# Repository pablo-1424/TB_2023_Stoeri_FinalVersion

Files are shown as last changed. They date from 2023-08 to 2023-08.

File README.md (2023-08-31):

# TB_2023_Stoeri_Public

## Information about the project

The goal of the project is to implement a system wich can detect if water is flowing and calculating for how long through a pipe. The amount of time of the water flow is then transmitted to TTN using the LoRa protocol.

A python script is able to store the received amount of time in a mySQL database from where two different graphs can be done.

## Used material

Chip : Murata CMWX1ZZABZ-091

Sensor : Bosch BMA400

DevKit with the Murata chip : B-L072Z-LRWAN1

DevKit with the sensor : SparkFun Triple Axis Accelerometer Breakout - BMA400

## Used software

IT-SDK from disk91 : https://github.com/disk91/stm32-it-sdk

## Content of the repository

### Folder 01_Report :

Contains the report of the thesis

### Folder 02_Code :

#### Folder EmbeddedSystem :

* Folder TB_noLoRa : Contains a functionnal code without the LoRa transmission
    
* Folder TB_Stoeri_FinalCode : Contains the final code including the LoRa transmission
  
#### Folder PythonScript :
  
* Folder SerialToGraph : Contains a code to make graphs with UART data
    
* Folder toFromSQL : Contains all the steps from TTN to dashboards threw a mySQL database

### Folder 03_Electronics :

  Contains the schematics of the PCB that has been made and wich is now used

### Folder 04_Mecanics :

  Contains all the CAD files of hardware used for this specific thesis

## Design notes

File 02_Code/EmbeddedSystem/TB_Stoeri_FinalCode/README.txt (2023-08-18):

Important files :
        Folder core/inc
                main.h : Main file, goToSleep function, timFunc function, and defines concerning the accelerometer and the water detection
                bma400func.h : Functions for the accelerometer
        
        Folder core/inc/it_sdk
                config.h : Configuration of the SDK
                configLoRaWan.h : LoRa configuration with SDK
                
        Folder core/src
                main.c : Main file, goToSleep function, and timFunc function
                project_main.c : LoRa send and Init
                bma400func.c : Functions for the accelerometer
                
        Folder stm32-it-sdk/src/stm32l_sdk
                gpio_wrapper.c : EXTI Pin12 callback
                
        Folder stm32-it-sdk/src/stm32l_sdk/timer
                timer.c : TIM6 callback
                
Startup procedure to program the final prototype :
        1) Open STM32 Cube IDE, ideally V1.9.0
        2) Import the project sensorLoRaSDK
        3) Compile in Release mode
        4) Wire the ST-Link V3 with the prototype
        5) Power the prototype
        6) With the STM32CubeProgrammer, connect the device to the PC
        7) Program the device with the .elf file wich has been generated by the compilation
        8) Connect an UART on the device (J2 connector -> See schematics)
        9) control that everything is working well

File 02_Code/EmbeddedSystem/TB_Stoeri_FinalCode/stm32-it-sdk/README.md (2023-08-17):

 Disk91 IoT_SDK not only for STM32

*Version 1.7 - in development. For stable version go to version-1.6 branch*

This project is a low level SDK with a harwdare abstraction layer designed to make IoT project. The purpose is to quickly be able to create communicating IoT device over LPWAN (LoRaWAn, Sigfox...) for fast prototyping but also being able to bring that firmware to production will all the necessary components avaoilable out-of-the-box. This SDK try to be fully configurable with header files. The objectif is to propose an abstraction layer between the software implementation and the MCU execution allowing to port the firmware on different plateform. 

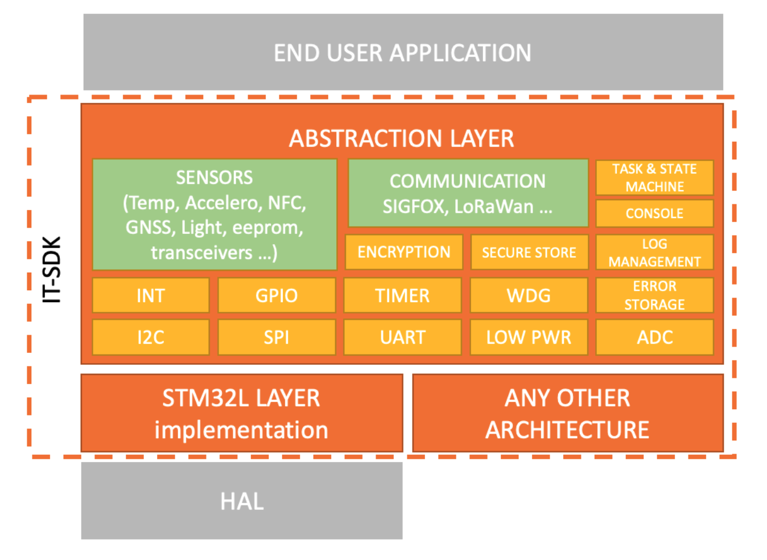
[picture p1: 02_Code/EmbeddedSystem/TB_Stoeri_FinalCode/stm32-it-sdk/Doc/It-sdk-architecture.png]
itsdk_architecture
 "IT-SDK Architecture"

The SDK is currently implementing STM32L architecture. The abstraction layer allows to quickly add new platforms. 

It implements different usefull function with (I hope) a cleaner code than the usual ST SDK components. 

Most is done to preserve code size, the SDK can target small flash MCU from 16KB for simple applications.

* IDE environement
  * open-source environment GCC / AC6 (Eclipse)
  * CubeIDE environment GCC / AC6 (Eclipse)
  * May work with any others

* Supported MCU functions
  * Low Power switch with regular auto-wakeup / LPUART / UART /GPIO Wake-up
  * RTC with calibration
  * EEprom for configuration backup
  * Watchdog 
  * Timers with calibration (hardware & software)
  * GPIO / SPI / I2C abstraction
  * Time update
  * Generic Interrupt Handler (hardware independant)

* Supported Advanced features
  * Task Scheduler
  * State Machine 
  * Multiple Serial console logger including Segger RTT
  * Error logger with NVM storage
  * Secured debug & configuration Console
  * Secured Storage in EEPROM for keys
  * End 2 End Sigfox & LoRaWan encryption
  * Configuration over serial for ID commissionning during manufacturing process
  * Accelerometer abstraction layer
  * Gnss abstraction layer
  
* Communication protocols interface
  * Sigfox ( clear-text, AES128-CTR, SPECK32, Sigfox-EAS128-CTR-Encryption )
  * LoRaWan ( LoRaWan-Encryption, EAS128-CTR, SPECK32 ) - join / uplink / downlink / ack

* Supported / tested platforms
  * STM32L011
  * STM32L053
  * STM32L072
  * STM32L052
  * MURATA CMWX1ZZABZ

* Supported drivers
  * eeprom
     * m95640
  * sigfox
     * s2lp (tested on RCZ1)
     * murata cmwx1zzabz (sx1276) (tested on RCZ1 & RCZ2)
  * lorawan
    * murata cmwx1zzabz (sx1276)
  * T / H / P
     * bosh bme280 & bmp280
     * omron 2smpb-02B
     * infineon DPS422
  * Light
     * Maxim Max44009
  * Current / Battery Pack
    * Maxim Max17205 / Max17201
  * NFC
  	 * ST25DV - block access / serial console over FTM & memory
  * Hall Effect
     * sl353
  * Accelerometer
     * STM - LIS2DH12
  * Gnss
     * Quectel L80 / L86
     * MediaTek 3333
       
* Supported stacks
  * lorawan
     * semtech stack
  * sigfox
     * sigfox stack

The second objective is to be able to port this SDK to different patform
to make it a portable SDK. The SDK have a it-sdk directory where everything needs to be portable. stm32l-sdk contains all the subfunctions specific to this platform.

# Project organization
Previously the devel branch was the living branch and master was stable. This way sound not optimal (at least for my github commit graph ;)/ So starting in 1.6 here is the new organization:
- devel is a bit advanced on master for not yet tested commit
- master is the new devel branch containing tested commit but not yet verified, you **must not** go in production with master.
- version branch for each new version + release 

# Start your project by configuring a skeleton with Cube Mx 

* Sys Clock Mux : HSI16
* Watchdog : configure IWDG with LSI 37KHz, IWDG_WINDOW value 4095, IWDG_PRESCALER value 256
* Rtc timer : TIM21 is enable with clock source internal for calibration
* LowPower : 
  * LPUART1/USART1/USART2 (Async 9600 - 8/N/1) for WakeUp => clock setting needs to be HSI and max speed needs to be 9600
  * RTC WakeUp => Activate ClkSource, Calendar, Internal WakeUp, Clk config : LSI, RTC/NVIC => Interrupt activated, Async prediv: 127, Sync prediv: 255
  * GPIO WakeUp => Activate the GPIO as ExtInterrupt, set with Pull & Trigger en Fall/Rise, activate NVIC EXI1_15
* adc : Select an adc like for temperature and Vcc to get the needed headers

When generating the Project
* Code generator:
  * select Generate peripheral initalization as par of .c/.h
  * Set all free pins as analog
* Advanced Settings:
  * Check Not Generated Function Call for ADC

# Import the SDK (this repository)

1. Clone this repository into the root of your project.
2. For the next configuration, you need to do it ifor both Debug *and* Release configuration 
3. Add in project properties >> C/C++ General >> Path&Symbol >> Source location >> the repository ItSdk Src directory.
4. Add in project properties >> C/C++ Build >> Settings >> Tool Settings >> MCU GCC Compiler >> Includes Path >>  Add the ItSdk Inc directory.
5. Add in project properties >> C/C++ Build >> Settings >> Tool Settings >> MCU GCC Assembler >> Includes Path >> Add the ItSdk Inc directory.
6. In C/C++ Build / Settings / Build Step / pre-build steps you can add the command _touch "${workspace_loc:/${ProjName}/stm32-it-sdk/Src/it_sdk/console/console.c}"_ this will update the compile date on every build
7. You can get detail on size of code generated on build by adding a post-build step _"arm-none-eabi-size  --format=sysV ${BuildArtifactFileName}"_
8. You can take a loop on [various stm32 code optimization](https://www.disk91.com/2020/technology/programming/code-optimization-with-stm32-cube-ide/) also. 

# Configure the SDK

1. Copy one of the *ItSdk/Src/project_main.c.template* file into Core/Src/project_main.c and make the modification you want to get started.
2. Copy the *ItSdk/Inc/it_sdk/config.h.template* file into *Core/Inc/it_sdk/config.h*
3. Copy the *ItSdk/Inc/it_sdk/configDrivers.h.template* file into *Core/Inc/it_sdk/configDrivers.h* [needed when using some of the drivers]
4. Copy the *ItSdk/Inc/it_sdk/configSigfox.h.template* file into *Core/Inc/it_sdk/configSigfox.h* [needed when using sigfox drivers]
5. Copy the *ItSdk/Inc/it_sdk/configLoRaWan.h.template* file into *Core/Inc/it_sdk/configLoRaWan.h* [needed when using LoRaWAn drivers]
6. Edit these files and fill the different settings according to your environment and your choices.

# Modify the Cube Mx skeleton
Things to not forget once a cubeMx project has been created
* Gpio.c
   - During deep-sleep, all the gpios not listed in _ITSDK_LOWPOWER_GPIO_X_KEEP_ will be switched analog. The gpio attached to devices (I2C,SPI...) will be reconfigured when these device will be reactivated but the standard gpio will need to be reconfigured.
   - By default the wake up procedure call *void MX_GPIO_Init(void)* function created by CubeMX. If the default setting is good for you you can keep it but you will have to remove the gpio SET & RESET functions.
   - Another solution (better) is to create a function named *void stm32l_lowPowerRestoreGpioConfig()*:
    ```C
    void stm32l_lowPowerRestoreGpioConfig() {

        /* GPIO Ports Clock Enable */
        __HAL_RCC_GPIOA_CLK_ENABLE();
        __HAL_RCC_GPIOB_CLK_ENABLE();
        __HAL_RCC_GPIOC_CLK_ENABLE();
        __HAL_RCC_GPIOH_CLK_ENABLE();

        // reconfigure the gpio deep-sleep have switched analog
        ...

        // reactivate the Interrupt line you need
        HAL_NVIC_SetPriority(EXTI0_1_IRQn, 0, 0);
        HAL_NVIC_EnableIRQ(EXTI0_1_IRQn);
        ...
        HAL_NVIC_SetPriority(EXTI4_15_IRQn, 0, 0);
        HAL_NVIC_EnableIRQ(EXTI4_15_IRQn);
   ```
  
* Main.c
   => includes
```C
  /* USER CODE BEGIN Includes */
	#include <it_sdk/config.h>
	#include <it_sdk/itsdk.h>
  /* USER CODE END Includes */
```  
   => main
```C
    MX_IWDG_Init();
  	/* USER CODE BEGIN 2 */
  	  itsdk_setup();
  	/* USER CODE END 2 */

  	/* Infinite loop */
  	/* USER CODE BEGIN WHILE */
  	while (1)
  	{
	  /* USER CODE END WHILE */
	  /* USER CODE BEGIN 3 */
	  itsdk_loop();
  	}
  	/* USER CODE END 3 */
```

Other modifications (need to be done on every CubeMx project regeneration):
  - GPIO - (in gpio.c) Cube Mx is setting/resetting the Gpio state on init. You need to manually comment the line in *gpio.c* to avoid the pin to be modified on MCU wake-up. The other solution is to let the gpio init as-is and add a function *void stm32l_lowPowerRestoreGpioConfig()* containing the gpio reconfiguration after wakeup.

  - ADC - if you choose to not use ADC_OPTIMIZED_CODE_FOR_SIZE : remove generated adc.c/h and remove adc references in main.c 
  
# Documentation

The documentation about the different components is available in **[/Doc](Doc/)** directory.
The function API are not documented in the _.h_ files but more generally in the _.c_ files.
Work in progress...

# Examples 

The examples are published on different Git repo to simplify the distribution of the SDK.
See **/Example** directory for a direct access to these ready to use projects.

# Version Upgrade
When upgrading the SDK from a new version, the main impact is to add the new Settings expected in the different
configuration file. Please find the different settings added version after version

## from version 1.7.0
### misc
- return code from I2C and SPI moved from I2C_XX to \_\_I2C_XX and SPI_XX to \_\_SPI_XX
- eeprom interface have a UserLand area. The config zone has been refactored to support version upgrade.

### config.h
 - ITSDK_WITH_GPIO_HANDLER / Enable the internal GPIO Handler - now you can disable it basically 
 - ITSDK_RADIO_POWER_OFFSET / Add an offset to radio Tx power - to compensate antenna loss transparently (global to all radios)
 - ITSDK_RADIO_CERTIF / Enable code and console options for radio certification

### configLoRaWan.h
 - ITSDK_LORAWAN_RX2DELAY_MOD / Ms Delay added to RX 2 Window Start for calibration

## from version 1.6.0
### project settings
 - Add in project properties >> C/C++ Build >> Settings >> Tool Settings >> MCU GCC Assembler >> Includes Path >> Add the ItSdk Inc directory.

### config.h
 - ITSDK_WITH_WDG / allows to disable the watchdog 
 - ITSDK_WITH_UART_RXIRQ / allows to enable an RX IRQ on Serial communications with internal circular buffer
 - ITSDK_WITH_UART_RXIRQ_BUFSZ / size of the RX IRQ circular buffer for each of the serial channel (power of two)
 - ITSDK_WITH_EXPERIMENTAL / activate or deactivate some experimental code by default set it to DISABLE
 - ITSDK_LOGGER_WITH_SEG_RTT / activate or deactive the segger RTT console (see segger.md file)
 - ITSDK_STATEMACHINE_STATIC / state machine optimization with definition stored in flaash instead of RAM

### configDriver.h
 - ITSDK_DRIVERS_WITH_ACCEL_DRIVER
 - ITSDK_DRIVERS_ACCEL_LIS2DH12 
 - ITSDK_DRIVERS_WITH_GNSS_DRIVER
 - ITSDK_DRIVERS_GNSS_QUECTEL
 - ITSDK_DRIVERS_MAX17205_CSN_TO_BAT
 - ITSDK_DRIVERS_O2SMPB

## from version 1.5.0
### config.h
- ITSDK_ADC_OPTIMIZE_SIZE
- ITSDK_ADC_OVERSAMPLING
- ITSDK_DEFAULT_REGION

### confgiDriver.h
- ITSDK_DRIVERS_SL353

### configLoRaWan.h
 - ITSDK_MURATA_TCXO_WARMUP
 - ITSDK_MURATA_WAKEUP_TIME
 - ITSDK_MURATA_ANTSW_RX_BANK (typo fixed)
 - ITSDK_MURATA_ANTSW_RX_PIN (typo fixed)
 - ITSDK_MURATA_ANTSW_TXBOOST_PIN (typo fixed)
 - ITSDK_MURATA_ANTSW_TXRFO_PIN (typo fixed)
 - header define name changed
 
### configSigfox.h
 - ITSDK_MURATA_ANTSW_RX_BANK (typo fixed)
 - ITSDK_MURATA_ANTSW_RX_PIN (typo fixed)
 - ITSDK_MURATA_ANTSW_TXBOOST_PIN (typo fixed)
 - ITSDK_MURATA_ANTSW_TXRFO_PIN (typo fixed)
 - ITSDK_SIGFOX_IF_TX_RCZ1
 - ITSDK_SIGFOX_IF_TX_RCZ3
 - ITSDK_SIGFOX_IF_TXRX_RCZ1
 - ITSDK_SIGFOX_IF_TXRX_RCZ3
 - ITSDK_MURATA_TCXO_WARMUP
 - ITSDK_SX1276_SFXWAKEUP_TIME
 - ITSDK_SIGFOX_MAXPOWER
 - ITDSK_SIGFOX_RCZ (removed)
 - ITSDK_MURATA_WAKEUP_TIME

# License 

This code and ItSdk are under GPLv3. You can use it freely, you can modify, redistribute but *you must* publish your source code. 

When included into a commercial product you have the following obligations:
- The commercial product must include as part of the documentation (Website + paper) and written on the packaging the following sentence  **build thanks to Disk91 IoT_SDK**  
- The commercial product documentation (Website + paper) a link to the Disk91 IoT_SDK github repository and a link with all the modified and added source code the product includes (following the GPLv3 licence)

Other licenses can be obtained by contacting me on [disk91.com](https://www.disk91.com). Non public licence allows you to be released from the previously described obligations.

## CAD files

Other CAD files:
04_Mecanics/Housing/boitierPCB.dwg
04_Mecanics/SheetMetal/onTubeFixation.dwg
04_Mecanics/Housing/couverclePCB.dwg
04_Mecanics/SheetMetal/onTubeFixationTiny.dwg
04_Mecanics/Housing/boitierPCB.ipt
04_Mecanics/Housing/couverclePCB.ipt
04_Mecanics/SheetMetal/onTubeFixation.ipt
04_Mecanics/SheetMetal/onTubeFixationTiny.ipt

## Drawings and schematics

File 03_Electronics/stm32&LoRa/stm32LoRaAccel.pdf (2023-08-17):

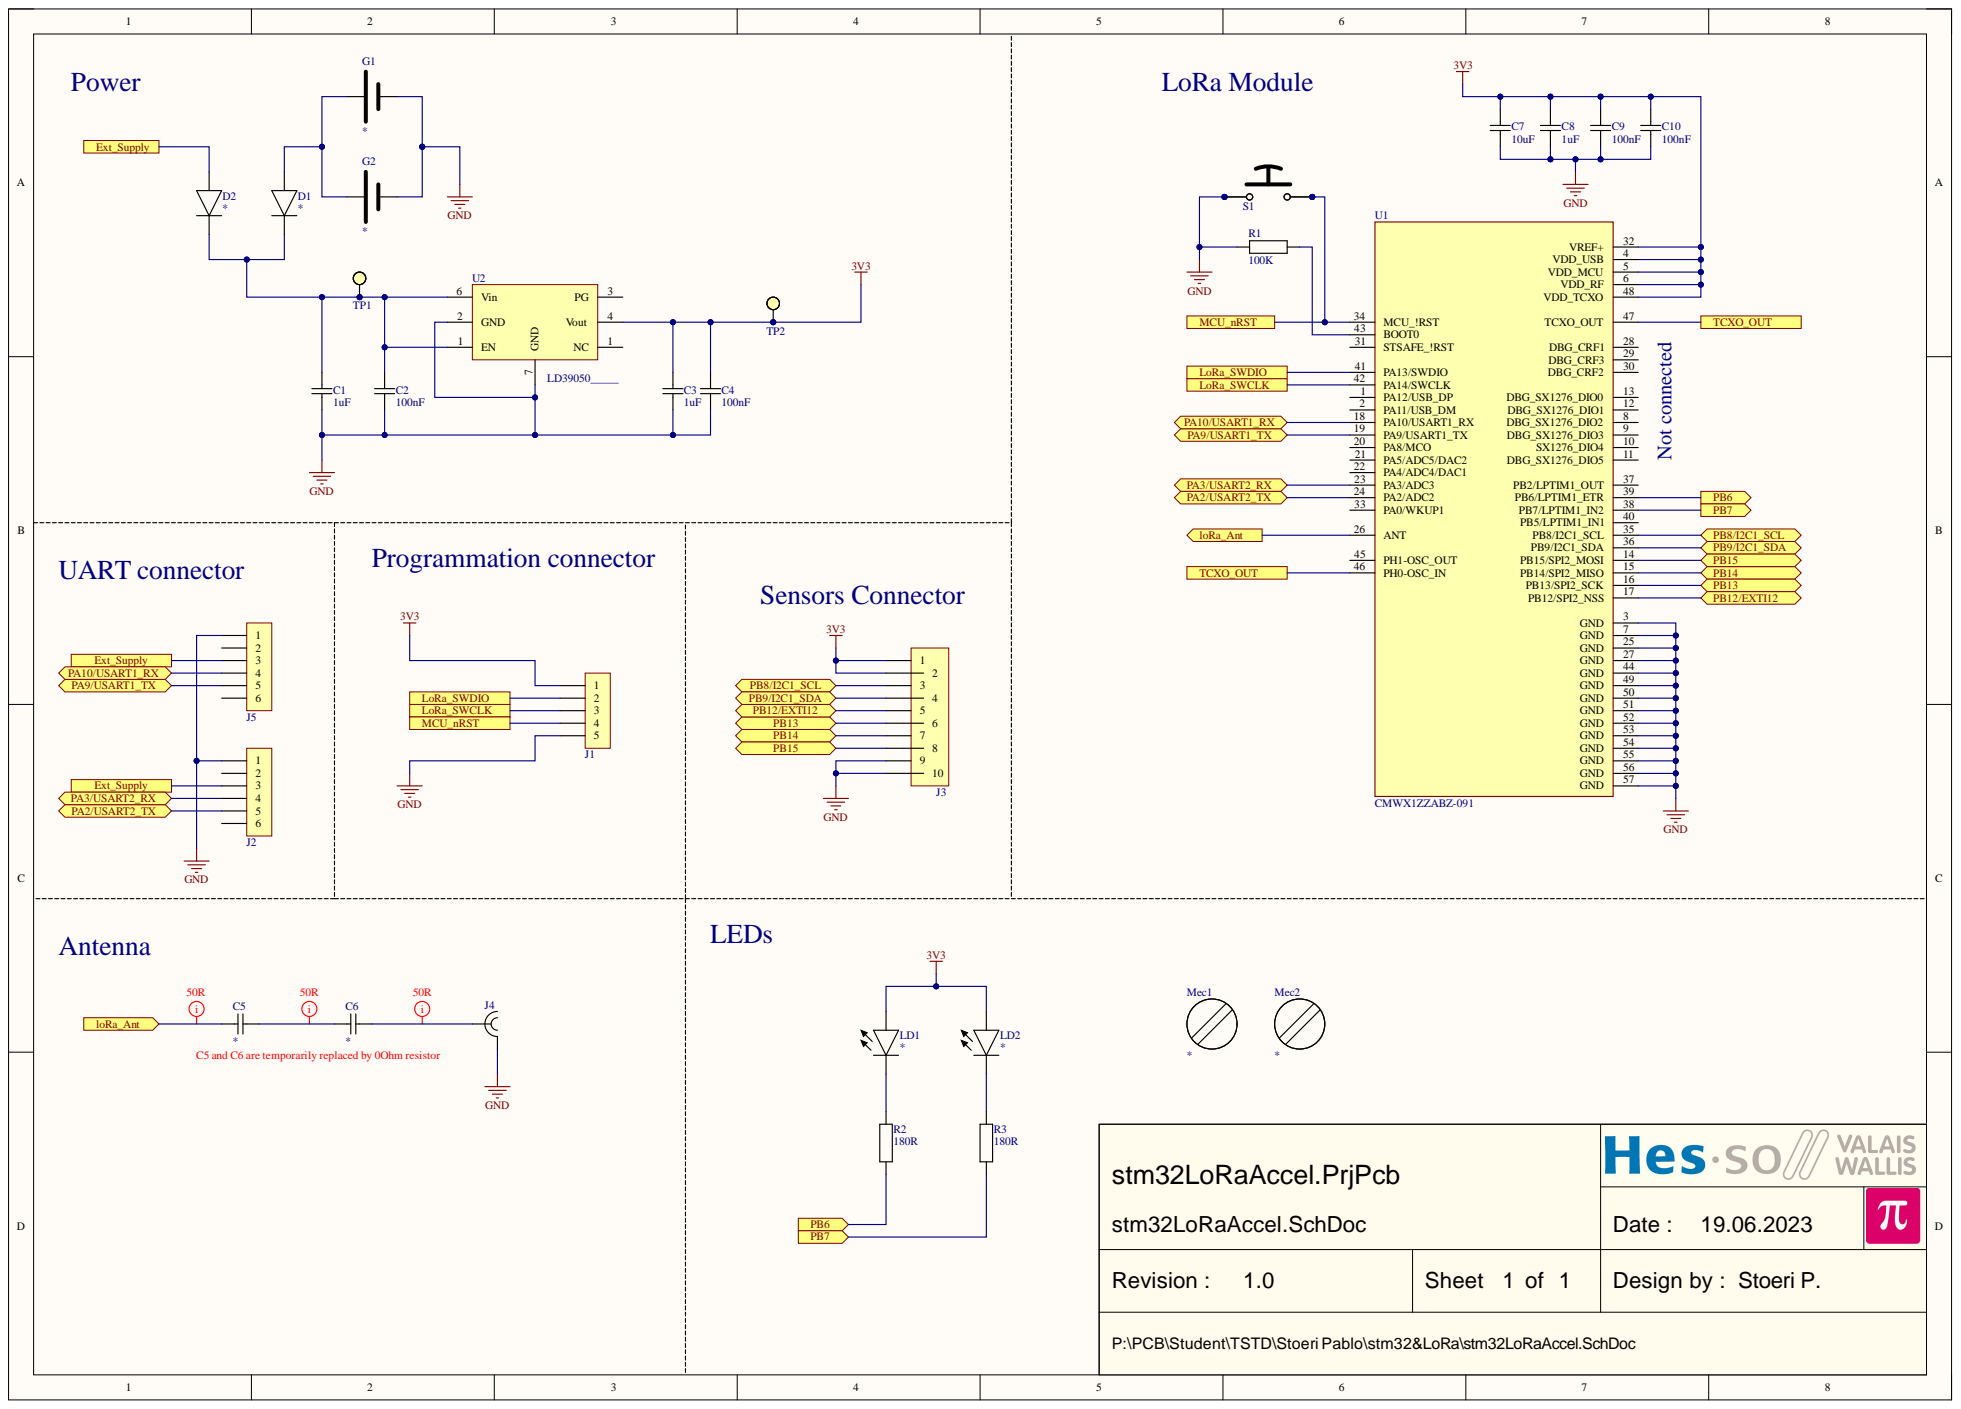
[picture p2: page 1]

MCU_nRST | BOOT0 43 | TCXO_OUT

C5 and C6 are temporarily replaced by 0Ohm resistor

stm32LoRaAccel.PrjPcb stm32LoRaAccel.SchDoc

Date : 19.06.2023

Revision : 1.0 | Sheet 1 of 1 | Design by : Stoeri P.

P:\PCB\Student\TSTD\Stoeri Pablo\stm32&LoRa\stm32LoRaAccel.SchDoc

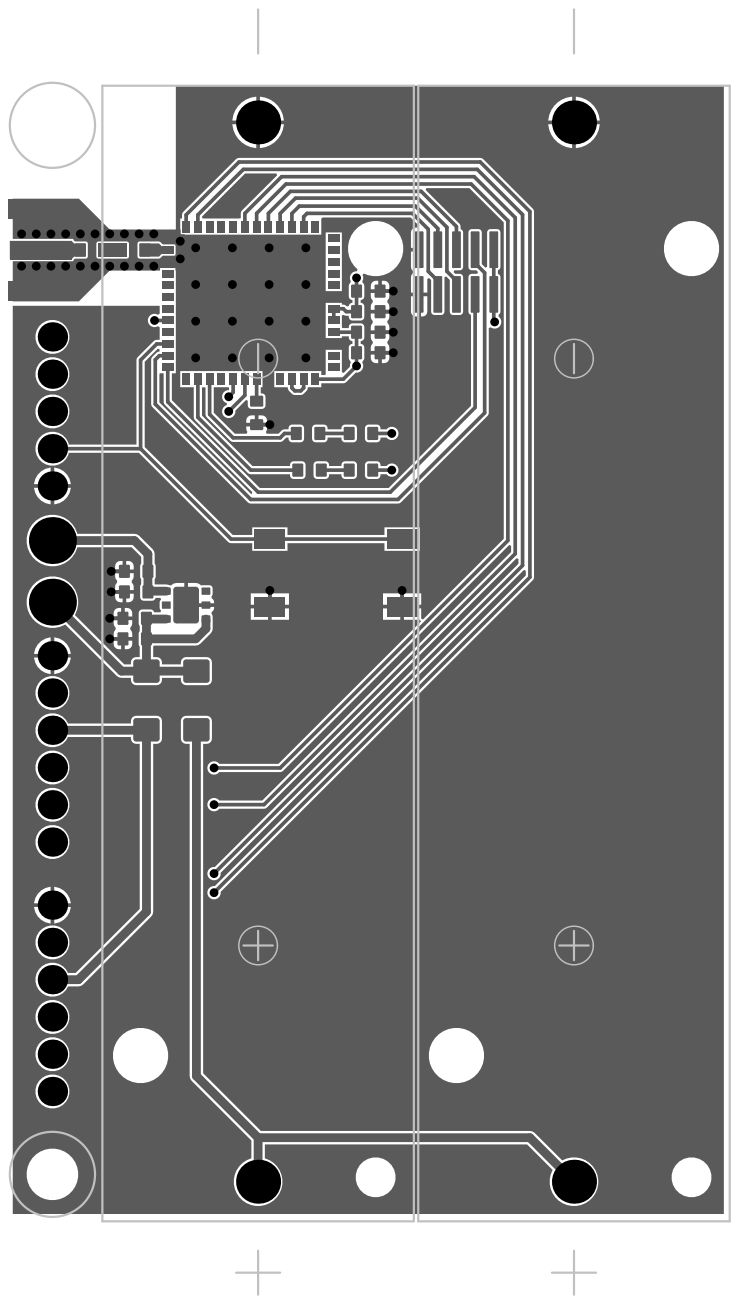
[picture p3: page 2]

Name | Description | Designator | Quantity | Footprint | TargetPrice | Manufacturer 1 | Manufacturer Part Number 1 | Manufacturer Lifecycle 1 | Supplier 1 | Supplier Part Number 1 | Supplier Unit Price 1 | Supplier Subtotal 1
1uF | Capacitor | C1, C3, C8 | 3 CAPACITOR 1608 REFLOW | | 0
100nF | Capacitor | C2, C4, C9, C10 | 4 CAPACITOR 1608 REFLOW | | 0
| Capacitor | C5, C6 | 2 CAPACITOR 1608 REFLOW | | 0
10uF | Capacitor | C7 | 1 CAPACITOR 1608 REFLOW | | 0
| Diode generic 2 leads | D1, D2 | 2 DIODE DO-214AC (SMA) | | 0
| Battery Generic | G1, G2 | 2 Battery Holder Keystone 18650 TH 1131 | | 0
| Plug connector | J1 | 1 PinHeader1x5 P2.54 | | 0
| Plug connector | J2, J5 | 2 PinHeader1x6 P2.54 | | 0
| Plug connector | J3 | 1 PinHeader2x5 P1.27 SMD H5.9 | | 0
CONSMA001-G | SMA EDGE SAMTEC SMA-J-P-H-ST-EM1 | J4 | 1 SMA EDGE SAMTEC SMA-J-P-H-ST-EM1 | | 0
| LED generic | LD1, LD2 | 2 LED 1608 REFLOW | | 0
| Screw Unconnected BN330 | Mec1, Mec2 | 2 Screw M3X5Unconnected | | 0
100K | Resistor | R1 | 1 RESISTOR 1608 REFLOW | | 0
180R | Resistor | R2, R3 | 2 RESISTOR 1608 REFLOW | | 0
| Push Button, 4 pins, 2 poles parrallèle | S1 | 1 Push Button C6.0x6.0 TE FSM-2J-SMA | | 0
| Test Point | TP1, TP2 | 2 Test Point Keystone Compact BLUE | | 0
CMWX1ZZABZ-091 | General ISM < 1GHz LoRaWan Transceiver Module 868MHz, 915MHz Surface Mount | U1 | 1 CMWX1ZZABZ-091 | | 0
LD39050_____ | 500mA low quiescent current and low noise voltage regulator | U2 | 1 DFN6 P0.95 T1.75X2.50 C3.0X3.0 H1.0 | | 0

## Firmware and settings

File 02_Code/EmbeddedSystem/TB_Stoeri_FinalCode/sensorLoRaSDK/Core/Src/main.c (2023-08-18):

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
/* Includes ------------------------------------------------------------------*/
#include "main.h"
#include "adc.h"
#include "i2c.h"
#include "rtc.h"
#include "spi.h"
#include "tim.h"
#include "usart.h"
#include "gpio.h"

/* USER CODE BEGIN Includes */
#include <it_sdk/config.h>
#include <it_sdk/itsdk.h>
#include <it_sdk/logger/logger.h>
#include <it_sdk/lorawan/lorawan.h>
#include <it_sdk/eeprom/sdk_config.h>
#include <stdio.h>
#include "bma400func.h"
#include <drivers/sx1276/sx1276.h>
/* USER CODE END Includes */


/* USER CODE BEGIN PV */
 uint8_t seconds[2] = {0};		// Amount of seconds of water flowing on 2 bytes
 uint8_t stopModeActiv;
/* USER CODE END PV */

void SystemClock_Config(void);
/**
  * @brief  The application entry point.
  * @retval int
  */
int main(void)
{
  /* MCU Configuration--------------------------------------------------------*/

  /* Reset of all peripherals, Initializes the Flash interface and the Systick. */
  HAL_Init();

  /* Configure the system clock */
  SystemClock_Config();

  /* Initialize all configured peripherals */
  MX_GPIO_Init();
  MX_RTC_Init();
  MX_SPI1_Init();
  MX_USART2_UART_Init();
  MX_ADC_Init();
  MX_TIM21_Init();
  MX_I2C1_Init();
  MX_TIM6_Init();
  /* USER CODE BEGIN 2 */

  itsdk_setup();

  // Water flow variables
  uint8_t waterOnOld = 0;								// 0 = off, 1 = on
  uint8_t waterOnNew = 0;								// 0 = off, 1 = on
  stopModeActiv = 0;

  // Due to LEDs wiring
  HAL_GPIO_WritePin(LD4_GPIO_Port, LD3_Pin, GPIO_PIN_SET);
  HAL_GPIO_WritePin(LD4_GPIO_Port, LD4_Pin, GPIO_PIN_SET);
  /* USER CODE END 2 */
  /* Infinite loop */
  /* USER CODE BEGIN WHILE */
  while (1)
  {
    /* USER CODE END WHILE */

    /* USER CODE BEGIN 3 */

	  // Checking if water is flowing
	  waterOnOld = waterOnNew;
	  waterOnNew = dataCheck();

	  // Checking if the water state has changed
	  if(waterOnNew != waterOnOld){
		  // Water state changed
		  if(waterOnNew == 1){
			  // Flow's on : start time to count second
			  HAL_TIM_Base_Start_IT(&htim6);
		  }else{
			  // Flow's off : stop timer
			  log_info("Seconds : %d%d\r\n", seconds[1],seconds[0]);
			  HAL_TIM_Base_Stop_IT(&htim6);
			  // Send LoRa if seconds amount is higher than 30s
			  if(seconds[0] > 30 || seconds[1]>0){
				  uint8_t loRaRet = loRaSendVal(seconds);
				  if(loRaRet == 1){
					  seconds[0] = 0;
					  seconds[1] = 0;
				  }
				  else{
					  log_info("seconds not sent");
				  }
			  }
		  }
	  }
	  // If water's definitely off, go to sleep
	  if(waterOnNew == waterOnOld && waterOnNew == 0){
		  //Control the status of the SX1276 Module
		  log_info("state : %d\r\n",SX1276GetStatus());
		  //Go sleep
		  goToStop();
	  }
  }
  /* USER CODE END 3 */
}

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
/* USER CODE BEGIN 4 */

// Function called by the TIM6 call back
void timFunc(uint8_t val){
	// Counting the amount of seconds with two bytes
	if(seconds[0] == 0xFF){
		seconds[0] = 0;
		seconds[1]++;
	}
	else {
		seconds[0]++;
	}
}

// Stop mode
void goToStop(){
	log_info("Go to sleep baby\r\n");
	stopModeActiv = 1;
	HAL_SuspendTick();
	HAL_PWR_EnterSTOPMode(PWR_MAINREGULATOR_ON, PWR_SLEEPENTRY_WFI);
}

/* USER CODE END 4 */
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


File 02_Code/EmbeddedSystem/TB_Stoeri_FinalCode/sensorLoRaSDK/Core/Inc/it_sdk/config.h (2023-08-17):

/* ==========================================================
 * config.h - SDK Configuration file
 * Project : Disk91 SDK
 * ----------------------------------------------------------
 * Created on: 2 sept. 2018
 *     Author: Paul Pinault aka Disk91
 * ----------------------------------------------------------
 * Copyright (C) 2018  Disk91
 *
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
 *
 * ==========================================================
 */

#ifndef IT_SDK_CONFIG_H_
#define IT_SDK_CONFIG_H_

#include <it_sdk/config_defines.h>

// ++++++++++++++++++++++++++++++++++++++++++++++++++++++++++++++++++++++++++++++++++++++++++++++++++++++++++++++++
// | SDK SETTING                   | USER SELECTED VALUE                  | SETTING DESCRIPTION                   |
// ++++++++++++++++++++++++++++++++++++++++++++++++++++++++++++++++++++++++++++++++++++++++++++++++++++++++++++++++
#define ITSDK_VERSION				"1.6.0-master"							// SDK Version String (do not change it)
#define ITSDK_VERSION_BYTE			0x16									//  SDK 1 Byte version corresponding to previous on (do not change it)

#define ITSDK_USER_VERSION			"0.1"									// CHANGE ME - Version of your firwmare
#define ITSDK_USER_VERSION_BYTE		0x01									// CHANGE ME - Version of your firwmare 4bits MAJOR / 4bits MINOR

#define ITSDK_CUBEMX_VERSION	    __CUBEMX_VERSION500						// Version of cube MX
#define ITSDK_PLATFORM 				__PLATFORM_STM32L0						// Hardware platform selection
#define ITSDK_DEVICE				__DEVICE_STM32L072XX					// Specific device
#define ITSDK_WITH_DRIVERS			__ENABLE								// Includes configDrivers.h
#define ITSDK_RAM_SIZE				(20*1024)								// RAM Memory size
#define ITSDK_EPROM_SIZE			(6*1024)								// EEPROM size
#define ITSDK_WITH_UART				( __UART_USART2 )						// Use USART2 for debug and console
#define ITSDK_WITH_UART_RXIRQ		__UART_USART2							// Setup some of the UART with IRQ enabled for RX
#define ITSDK_WITH_UART_RXIRQ_BUFSZ 64										// Size of the UART IRQ RX circular buffer (power of 2)
#define ITSDK_WITH_RTC				__RTC_ENABLED							// The Rtc is usd in the firmware
#define ITSDK_WITH_CLK_ADJUST		__ENABLE								// The RTC (and wtachdog) is calibrated
#define ITSDK_RTC_CLKFREQ			32768									// RTC clock source frequency
#define ITSDK_CLK_BEST_SOURCE		__CLK_BEST_SRC_RTC						// The RTC is the most accurate clk source to ADJUST Others
#define ITSDK_CLK_CORRECTION		1000									// correct clock with 1200 o/oo (+20%) of the ticks (used when clk_adjust = 0 or for RTC when CLK_BEST_SRC_RTC)
#define ITSDK_WITH_ADC				__ADC_ENABLED							// Use of Adc (includes the structures)
#define ITSDK_ADC_OPTIMIZE_SIZE		__ENABLE								// When __ENABLE adc code is optimized for code size (when relevant)
#define ITSDK_ADC1_PIN				65										// Map the channel for ADC on PIN 14 (PA0)
#define ITSDK_ADC_OVERSAMPLING		16										// Number of ADC read time before averaging
#define ITSDK_VDD_MV				3300									// VDD value in mV
#define ITSDK_VBAT_MIN				2000									// MIN value for VBAT in mv
#define ITSDK_VBAT_MAX				3300									// MAX value for VBAT in mv
#define ITSDK_VBAT_ADC_PIN			-1										// ADC pin used to measure VBAT (if -1 assume VBAT = VCC)
#define ITSDK_WITH_SPI				__SPI_ENABLED							// Use SPI (inludes the strutures)
#define ITSDK_SPI_HANDLER_TYPE		SPI_HandleTypeDef						// The name of the Spi structure to be used for the targeted MCU
#define ITSDK_SPI_TIMEOUT			100										// SPI transaction timeout in ms
#define ITSDK_WITH_I2C				__I2C_ENABLED								// I2C is enabled (__I2C_NONE / __I2C_ENABLED )
#define ITSDK_I2C_HANDLER_TYPE		I2C_HandleTypeDef						//    The name of the I2C structure to be used for the targeted MCU
#define ITSDK_I2C_TIMEOUT			100										//    I2C transaction timeout in ms
#define ITSDK_WITH_HW_TIMER			__TIMER_ENABLED							// Use Hardware Timer
#define ITSDK_HW_TIMER1_HANDLE		htim21									// Timer handler to be used as primary timer
#define ITSDK_HW_TIMER1_ID			21										// Timer hadware 1 - id/name
#define ITSDK_HW_TIMER1_FREQ		32000000								// Primary timer base frequency
#define ITSDK_HW_TIMER1_MAX			2024									// Timer's counter max value ( 2^size )
#define ITSDK_TIMER_SLOTS			5										// Maximum number of SOFT TIMER available in parallel - 0 disable SOFT TIMER code
#define ITSDK_WITH_WDG				__WDG_NONE								// Allows to disable the watchdog
#define ITSDK_WDG_MS				0									// WatchDog time out in ms 1 --> 28000 / 0 to disable
#define ITSDK_WDG_CLKFREQ			37000									// Watchdog clock source frequency
#define ITSDK_CORE_CLKFREQ			32000000								// Core Frequency of the chip
#define ITSDK_WITH_EXPERIMENTAL 	__DISABLE								// activate or deactivate some experimental code by default set it to DISABLE
#define ITSDK_WITH_GPIO_HANDLER		__ENABLE								// Enable the internal GPIO Handler, when disable you need to map it manually
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

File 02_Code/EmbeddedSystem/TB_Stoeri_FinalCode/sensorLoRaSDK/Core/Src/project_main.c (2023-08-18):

/* ==========================================================
 * project_main.c - 
 * Project : Disk91 SDK
 * ----------------------------------------------------------
 * Created on: 6 sept. 2018
 *     Author: Paul Pinault aka Disk91
 * ----------------------------------------------------------
 * Copyright (C) 2018 Disk91
 *
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
 * Add a such file in the main Src directory for executing
 * you own workload.
 *
 * ==========================================================
 */
#include <it_sdk/config.h>
#include <it_sdk/itsdk.h>
#include <it_sdk/time/time.h>
#include <it_sdk/logger/logger.h>
#include <it_sdk/sched/scheduler.h>
#include <it_sdk/statemachine/statemachine.h>
#include <it_sdk/eeprom/eeprom.h>
#include <it_sdk/eeprom/sdk_config.h>

#include <it_sdk/lorawan/lorawan.h>
#include <it_sdk/encrypt/encrypt.h>
#include <it_sdk/eeprom/securestore.h>
#include <it_sdk/lowpower/lowpower.h>
#include <drivers/sx1276/sx1276.h>
#include "bma400func.h"


#define COMFREQS	(2*60*1000)
#define TASKDELAYMS	(500)

struct state {
	uint8_t 		led;
	uint32_t  		loops;
	int32_t			lastComMS;
	itsdk_bool_e	setup;
} s_state;


#define LED1_PORT 	__BANK_B
#define LED1_PIN 	__LP_GPIO_5
#define LED2_PORT 	__BANK_A
#define LED2_PIN 	__LP_GPIO_5
#define LED3_PORT 	__BANK_B
#define LED3_PIN 	__LP_GPIO_6
#define LED4_PORT 	__BANK_B
#define LED4_PIN 	__LP_GPIO_7
#define BUTTON_PORT	__BANK_B
#define BUTTON_PIN 	__LP_GPIO_2

uint8_t loRaSendVal(uint8_t *valToTransmit){
	uint8_t devEui[8] = {0};
	itsdk_lorawan_getDeviceEUI(devEui);

	log_info("Init LoRawan Stack ");
	itsdk_lorawan_init_t r;
	#ifdef ITSDK_LORAWAN_CHANNEL
		static itsdk_lorawan_channelInit_t channels= ITSDK_LORAWAN_CHANNEL;
		r = itsdk_lorawan_setup(itsdk_config.sdk.activeRegion,&channels);
	#else
		r = itsdk_lorawan_setup(itsdk_config.sdk.activeRegion,NULL);
	#endif
	if ( r == LORAWAN_INIT_SUCESS ) {
		log_info("success\r\n");
	} else {
		log_info("failed\r\n");
	}

	// Bytes to send LoRa : 0xFF & 0x88 is to recognise on for the part TTN to mySQL
	uint8_t t[20] = {valToTransmit[1],valToTransmit[0],0,0xFF,0,0x88,0,0,0,0,0,0,0,0,0,0,0,0,0,0};
	if ( !itsdk_lorawan_hasjoined() ) {
		log_info("Connecting LoRaWAN ");

		if ( itsdk_lorawan_join_sync() == LORAWAN_JOIN_SUCCESS ) {
			log_info("success\r\n");
			log_info("Fire a LoRaWAN message ");
			uint8_t port;
			uint8_t size=16;
			uint8_t rx[16];
			itsdk_lorawan_send_t r = itsdk_lorawan_send_sync(
				t,						// Payload
				16,						// Payload size
				1,						// Port
				__LORAWAN_DR_5,			// Speed
				LORAWAN_SEND_CONFIRMED,	// With a ack
				ITSDK_LORAWAN_CNF_RETRY,// And default retry
				&port,					// In case of reception - Port (uint8_t)
				&size,					// In case of reception - Size (uint8_t) - init with buffer max size
				rx,						// In case of recpetion - Data (uint8_t[] bcopied)
				PAYLOAD_ENCRYPT_NONE	// End to End encryption mode
			);
			if ( r == LORAWAN_SEND_SENT || r == LORAWAN_SEND_ACKED ) {
				log_info("success\r\n",r);
				return 1;
			} else {
				return 0;
				log_info("failed (%d)\r\n",r);
			}
		}else {
			log_info("failed\r\n");
		}
	} else {
		log_info("Fire a LoRaWAN message ");
		uint8_t port;
		uint8_t size=16;
		uint8_t rx[16];
		itsdk_lorawan_send_t r = itsdk_lorawan_send_sync(
				t,						// Payload
				16,						// Payload size
				1,						// Port
				__LORAWAN_DR_5,			// Speed
				LORAWAN_SEND_CONFIRMED,	// With a ack
				ITSDK_LORAWAN_CNF_RETRY,// And default retry
				&port,					// In case of reception - Port (uint8_t)
				&size,					// In case of reception - Size (uint8_t) - init with buffer max size
				rx,						// In case of recpetion - Data (uint8_t[] bcopied)
				PAYLOAD_ENCRYPT_NONE	// End to End encryption mode
		);
		if ( r == LORAWAN_SEND_SENT || r == LORAWAN_SEND_ACKED ) {
			log_info("success\r\n",r);
			return 1;
		} else {
			log_info("failed (%d)\r\n",r);
			return 0;
		}
	}
}


// =====================================================================
// Setup

void project_setup() {
	log_info("Hello Boss let's setup \r\n");
	SX1276SetRfTxPower(20);
	bma400_InitConfig();

	s_state.loops = 0;
	s_state.lastComMS = COMFREQS;
	s_state.setup = BOOL_FALSE;

}


/**
 * Project loop may not contain functional stuff
 * Keep in this loop only really short operations
 */
void project_loop() {
    itsdk_lorawan_loop();
}

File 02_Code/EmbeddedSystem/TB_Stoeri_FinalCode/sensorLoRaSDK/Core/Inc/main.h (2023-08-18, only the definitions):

#define RADIO_NSS_Pin GPIO_PIN_15
#define RADIO_NSS_GPIO_Port GPIOA
#define RADIO_SCLK_Pin GPIO_PIN_3
#define RADIO_SCLK_GPIO_Port GPIOB
#define LD1_Pin GPIO_PIN_5
#define LD1_GPIO_Port GPIOB
#define RADIO_TCXO_VCC_Pin GPIO_PIN_12
#define RADIO_TCXO_VCC_GPIO_Port GPIOA
#define RADIO_DIO_0_Pin GPIO_PIN_4
#define RADIO_DIO_0_GPIO_Port GPIOB
#define RADIO_DIO_0_EXTI_IRQn EXTI4_15_IRQn
#define LD3_Pin GPIO_PIN_6
#define LD3_GPIO_Port GPIOB
#define RADIO_DIO_3_Pin GPIO_PIN_13
#define RADIO_DIO_3_GPIO_Port GPIOC
#define RADIO_DIO_3_EXTI_IRQn EXTI4_15_IRQn
#define LD4_Pin GPIO_PIN_7
#define LD4_GPIO_Port GPIOB
#define RADIO_ANT_SWITCH_TX_BOOST_Pin GPIO_PIN_1
#define RADIO_ANT_SWITCH_TX_BOOST_GPIO_Port GPIOC
#define RADIO_RESET_Pin GPIO_PIN_0
#define RADIO_RESET_GPIO_Port GPIOC
#define RADIO_DIO_1_Pin GPIO_PIN_1
#define RADIO_DIO_1_GPIO_Port GPIOB
#define RADIO_DIO_1_EXTI_IRQn EXTI0_1_IRQn
#define B1_Pin GPIO_PIN_2
#define B1_GPIO_Port GPIOB
#define RADIO_ANT_SWITCH_RX_Pin GPIO_PIN_1
#define RADIO_ANT_SWITCH_RX_GPIO_Port GPIOA
#define RADIO_ANT_SWITCH_TX_RFO_Pin GPIO_PIN_2
#define RADIO_ANT_SWITCH_TX_RFO_GPIO_Port GPIOC
#define RADIO_MOSI_Pin GPIO_PIN_7
#define RADIO_MOSI_GPIO_Port GPIOA
#define STLINK_RX_Pin GPIO_PIN_2
#define STLINK_RX_GPIO_Port GPIOA
#define SENSOR_INT_Pin GPIO_PIN_12
#define SENSOR_INT_GPIO_Port GPIOB
#define SENSOR_INT_EXTI_IRQn EXTI4_15_IRQn
#define RADIO_DIO_2_Pin GPIO_PIN_0
#define RADIO_DIO_2_GPIO_Port GPIOB
#define RADIO_DIO_2_EXTI_IRQn EXTI0_1_IRQn
#define RADIO_MISO_Pin GPIO_PIN_6
#define RADIO_MISO_GPIO_Port GPIOA
#define LD2_Pin GPIO_PIN_5
#define LD2_GPIO_Port GPIOA
#define STLINK_TX_Pin GPIO_PIN_3
#define STLINK_TX_GPIO_Port GPIOA
#define SER_BUF_SIZE		20
#define F_SAMP 				800
#define FIFO_SIZE 			1024
#define ACC_ADDR 			0b0010100<<1
#define REG_CHIPID 			0x00
#define REG_ACC_X_LSB			0x04
#define REG_ACC_X_MSB 			0x05
#define REG_ACC_Y_LSB 			0x06
#define REG_ACC_Y_MSB 			0x07
#define REG_ACC_Z_LSB 			0x08
#define REG_ACC_Z_MSB 			0x09
#define REG_FIFO_LENGTH0		0x12
#define REG_FIFO_LENGTH1		0x13
#define REG_FIFO_DATA			0x14
#define REG_ACC_CONFIG0			0x19
#define REG_ACC_CONFIG1			0x1A
#define REG_ACC_CONFIG2			0x1B
#define REG_INT_CONFIG0			0x1F
#define REG_INT_CONFIG1			0x20
#define REG_INT1_MAP			0x21
#define REG_INT12_IO_CTRL		0x24
#define REG_FIFO_CONFIG0		0x26
#define REG_GEN1INT_CONFIG0		0x3F
#define REG_GEN1INT_CONFIG1		0x40
#define REG_GEN1INT_CONFIG2		0x41
#define REG_GEN1INT_CONFIG3		0x42
#define REG_GEN1INT_CONFIG31	0x43
#define REG_ACTCHCONFIG0		0x55
#define REG_ACTCHCONFIG1		0x56
#define THRESHOLD				30
#define MIDDLE_VAL				1024
#define MIN_COUNT				14

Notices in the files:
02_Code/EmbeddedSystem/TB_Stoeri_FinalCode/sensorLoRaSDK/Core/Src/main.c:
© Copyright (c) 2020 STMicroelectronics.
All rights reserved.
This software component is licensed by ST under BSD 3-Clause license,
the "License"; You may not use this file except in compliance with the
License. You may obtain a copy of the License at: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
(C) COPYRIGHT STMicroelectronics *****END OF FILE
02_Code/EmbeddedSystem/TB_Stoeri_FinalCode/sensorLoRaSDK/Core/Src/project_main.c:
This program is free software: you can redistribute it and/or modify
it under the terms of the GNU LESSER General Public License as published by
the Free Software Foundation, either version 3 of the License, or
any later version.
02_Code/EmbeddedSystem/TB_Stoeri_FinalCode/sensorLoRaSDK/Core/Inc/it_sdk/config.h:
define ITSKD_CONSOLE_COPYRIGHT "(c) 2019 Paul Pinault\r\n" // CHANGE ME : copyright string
